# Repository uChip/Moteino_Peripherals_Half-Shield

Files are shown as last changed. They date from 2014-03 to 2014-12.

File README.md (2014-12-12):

# Moteino Peripherals Half-Shield  

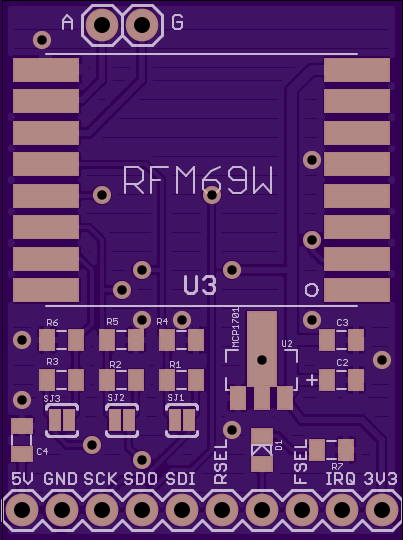
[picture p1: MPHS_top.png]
Moteino Peripherals Half-Shield top side
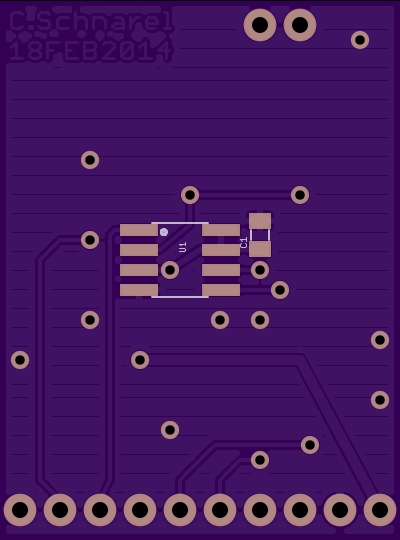
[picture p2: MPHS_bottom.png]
Moteino Peripherals Half-Shield bottom side
___  

After making breakout boards for the RFM12B & [RFM69](https://github.com/uChip/RFM69W_BOB) and getting a taste of what those radios can do, I decided I would like to experiment more with [Felix Rusu's software](http://www.lowpowerlab.com).  Of particular interest is the software that Felix has created that enables an Arduino based device to be reprogrammed remotely and wirelessly**.  Now I could just buy a few of Felix's fine [Moteinos](http://lowpowerlab.com/moteino/), but I already have a bunch of [Unos](https://www.sparkfun.com/products/11021), [Minis](https://www.sparkfun.com/products/11113), [Pro Micros](https://www.sparkfun.com/products/12640) and such.  So instead I decided to do a new version of the radio breakout board that adds the flash memory chip.  While I was at it, I also added the LED on D9 so that code would work too.  

I call the board a half-shield.  That is because it will plug directly into an UNO header (plus a couple of wires) but takes up only half the pins.  

Here is the Moteino Peripherals Half-Shield plugged into an Arduino clone, the [RedBoard](https://www.sparkfun.com/products/11575) from SparkFun.  

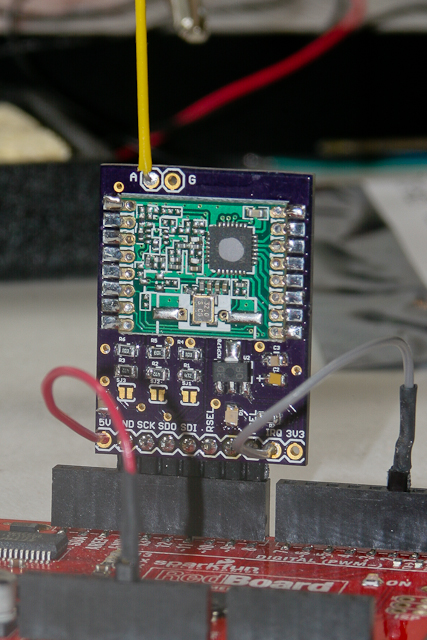
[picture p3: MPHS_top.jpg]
MPHS top side
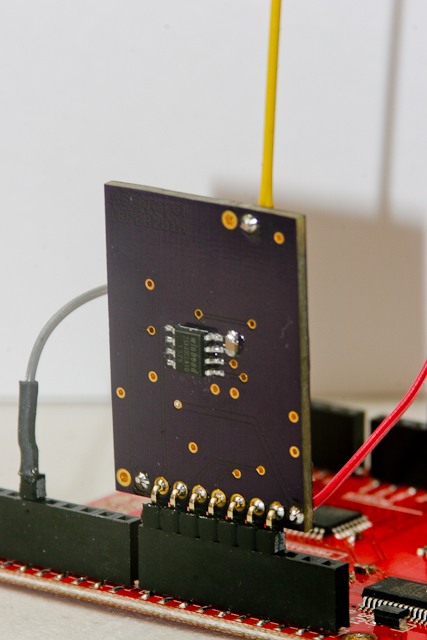
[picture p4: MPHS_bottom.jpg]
MPHS bottom side
___  

This repo includes Eagle CAD PCB design files for the board.  The board converts the RFM69W radio transceiver from SMT to 0.1" breadboard format and provides [optional] level translation for use with 5V controllers.  Note that you cannot solder the RFM12B or the RFM69CW radio modules to this board.  Use the RFM69W or RFM69HW modules instead.  

The board also has provision on the bottom side for a conforming SOIC-8 package flash memory part such as the Winbond W25X40CLSNIG.  

See the following links for Arduino drivers for the RFM69W and flash memory  
  * https://github.com/LowPowerLab/RFM69  
  * https://github.com/LowPowerLab/SPIFlash  

### 5V Hookup  
Hookup of the breakout board to 5V Arduino SPI connection.  All board components populated.  Solder-jumpers left open.  

	Arduino			Half-Shield  
	  5V	-->		  5V  
	  GND	<-->	  GND  
	  D13	-->		  SCK  
	  D12	<--		  SDO  
	  D11	-->		  SDI  
	  D10	-->		  RSEL  
	  D9	-->		  LED  
	  D8	-->		  FSEL  
	  D2	<--		  IRQ  
	  		<--		  3V3  
 
### 3.3V Hookup  
Hookup of the breakout board to 3.3V Arduino SPI connection.  On PCB populate only radio, flash memory, C1, C2 and C3.  Short the pads on the solder-jumpers.  

	Arduino			Half-Shield  
	  NC	 		  5V  
	  GND	<-->	  GND  
	  D13	-->		  SCK  
	  D12	<--		  SDO  
	  D11	-->		  SDI  
	  D10	-->		  RSEL  
	  D9	-->		  LED  
	  D8	-->		  FSEL  
	  D2	<--		  IRQ  
 	  3.3V	-->		  3V3  

## Order PCBs  

You can order this PCB directly from OSH Park.  Click on the following link.  
  * Radio Breakout - http://oshpark.com/shared_projects/AadEx5fd  

See Bill of Materials file in repo for parts list.  

## Status  
  * PCB layout has been tested to be functional using the Low Power Lab example code for RFM69 and SPIFlash.  

## File Formats  

Design files are in "CadSoft EAGLE PCB Design Software" .brd and .sch formats.  
A free version of the software can be downloaded from www.cadsoftusa.com.  

schematic  
schematic  

PCB  
PCB   

## Distribution License  

You may use this PCB design however you like but no liability is accepted.  

## Notes:

** Arduino wireless reprogramming requires a custom bootloader.  Read more about it at http://LowPowerLab.com

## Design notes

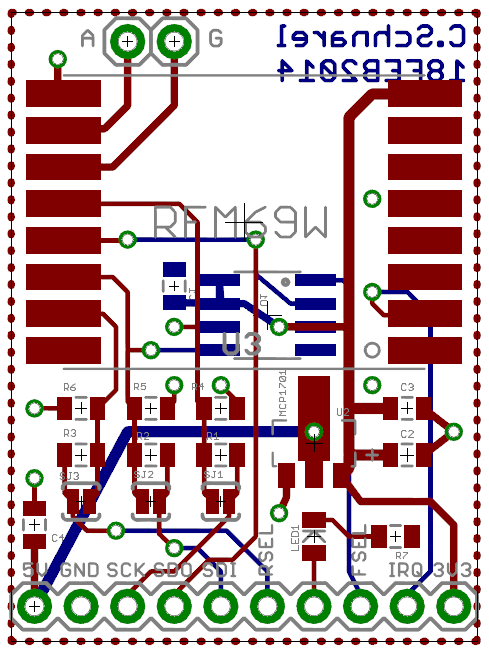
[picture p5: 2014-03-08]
MPHS_brd.PNG

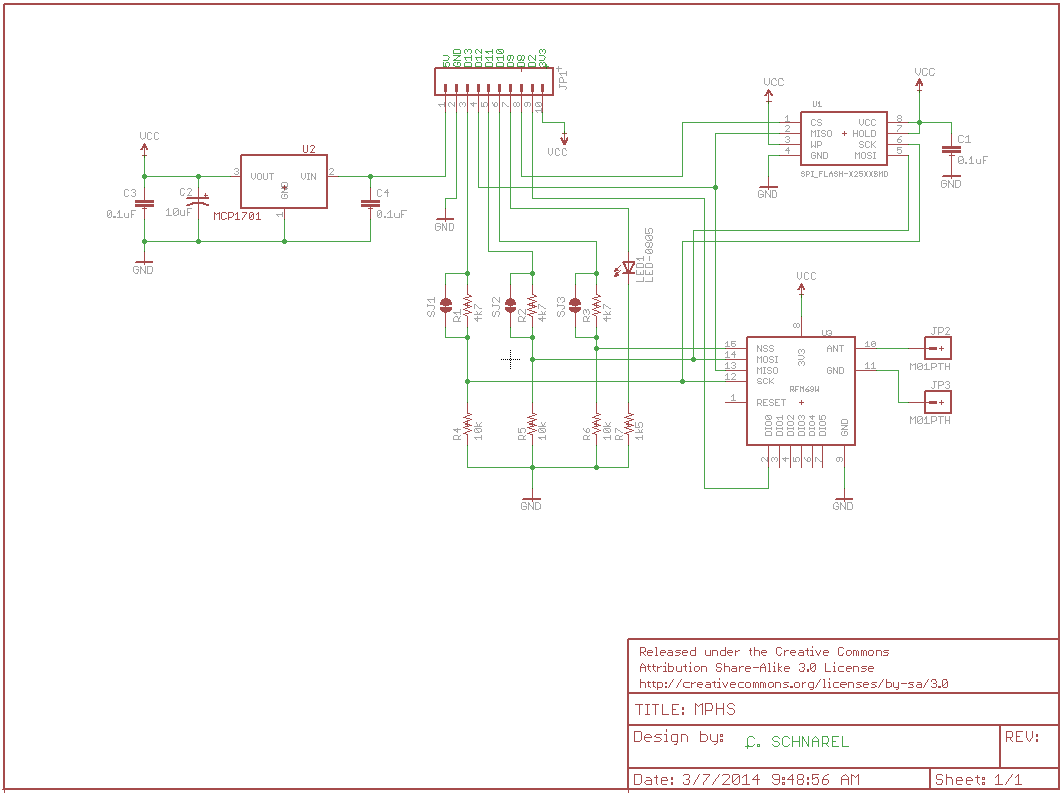
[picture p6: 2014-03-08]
MPHS_sch.PNG

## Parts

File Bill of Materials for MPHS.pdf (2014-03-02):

## Bill of Materials for Moteino Peripherals Half-Shield

## By Component ID

Part | Value | Device | Package | Description | Comment
C1 | 0.1uF | CAP0805 | 0805 | Capacitor
C2 | 10uF | CAP_POL0805 | 0805-POL | Capacitor, Tantalum | Could likely substitute electrolytic with no ill effects.
C3 | 0.1uF | CAP0805 | 0805 | Capacitor
C4 | 0.1uF | CAP0805 | 0805 | Capacitor
JP1 | 10 or 7 pins | 1X07_RIGHT_ANGLE | | Header 10 or 7 | To plug into a breadboard populate all 10 pins. To plug into Arduino as a shield populate 7 pins.
R1 | 4k7 | RESISTOR0805-RES | 0805 | Resistor
R2 | 4k7 | RESISTOR0805-RES | 0805 | Resistor
R3 | 4k7 | RESISTOR0805-RES | 0805 | Resistor
R4 | 10k | RESISTOR0805-RES | 0805 | Resistor
R5 | 10k | RESISTOR0805-RES | 0805 | Resistor
R6 | 10k | RESISTOR0805-RES | 0805 | Resistor
R7 | 1k5 | RESISTOR0805-RES | 0805 | Resistor
U1 | SPI_FLASH | SPI_FLASH_X25XXSMD | SO08 | IC | 8pin SPI Flash series X25XX
U2 | MCP1701 | MCP1701 | SOT-89 | Voltage Regulator, LDO | 3.3volt
U3 | RFM69W | RFM69W | Module | Radio Transceiver Module | Untested, but you can likely substitute RFM69HW for more power.

## Order List

Qty | Parts | Value | Mfg Part # | Description / Vendor
1 | JP1 | 10 or 8-pins | | Break Away Male Headers - Right Angle https://www.sparkfun.com/products/553[/
1 | PCB | | Moteino Peripherals Half-Shield | http://oshpark.com/shared_projects/AadEx5fd
3 | C1, C3, C4 | 0.1uF | C2012X7R2A104K125AA | CAP CER 0.1UF 100V 10% X7R 0805 Digi-Key #445-1418-1-ND
3 | R4, R5, R6 | 10k | ERJ-6GEYJ103V | RES 10K OHM 1/8W 5% 0805 SMD Digi-Key #P10KACT-ND
1 | C2 | 10uF | F951A106MRAAQ2 | CAP TANT 10UF 10V 20% 0805 Digi-Key #478-8418-1-ND
3 | R1, R2, R3 | 4k7 | ERJ-6GEYJ472V | RES 4.7K OHM 1/8W 5% 0805 SMD Digi-Key #P4.7KACT-ND
1 | R7 | 1k5 | RC2012J152CS | RES 1.5K OHM 1/8W 5% 0805 SMD Digi-Key #1276-5533-1-ND
1 | U2 | MCP1701 | MCP1701AT-3302I/MB | IC REG LDO 3.3V 0.15A SOT89-3 Digi-Key #MCP1701AT-3302I/MBCT-ND
1 | U3 | RFM69W | RFM69W-S2 | http://lowpowerlab.com/shop/RFM69W
1 | U1 | 4Mbit Flash | W25X40CLSNIG | IC FLASH 4MBIT 104MHZ 8SOIC Digi-Key #W25X40CLSNIG-ND

Note that all parts are "or equivalent". These are the parts I tested with, but you can probably substitute parts with no impact on performance. For instance, any 0805 package 10k resistor would be fine.

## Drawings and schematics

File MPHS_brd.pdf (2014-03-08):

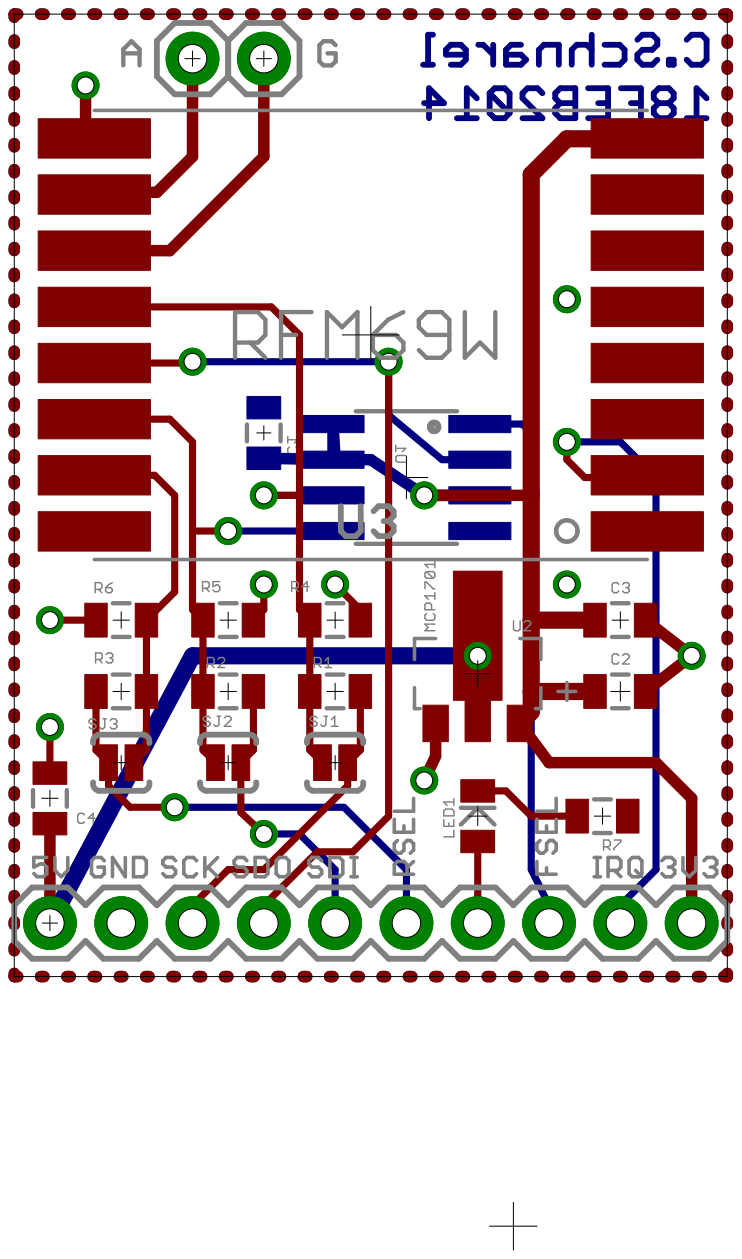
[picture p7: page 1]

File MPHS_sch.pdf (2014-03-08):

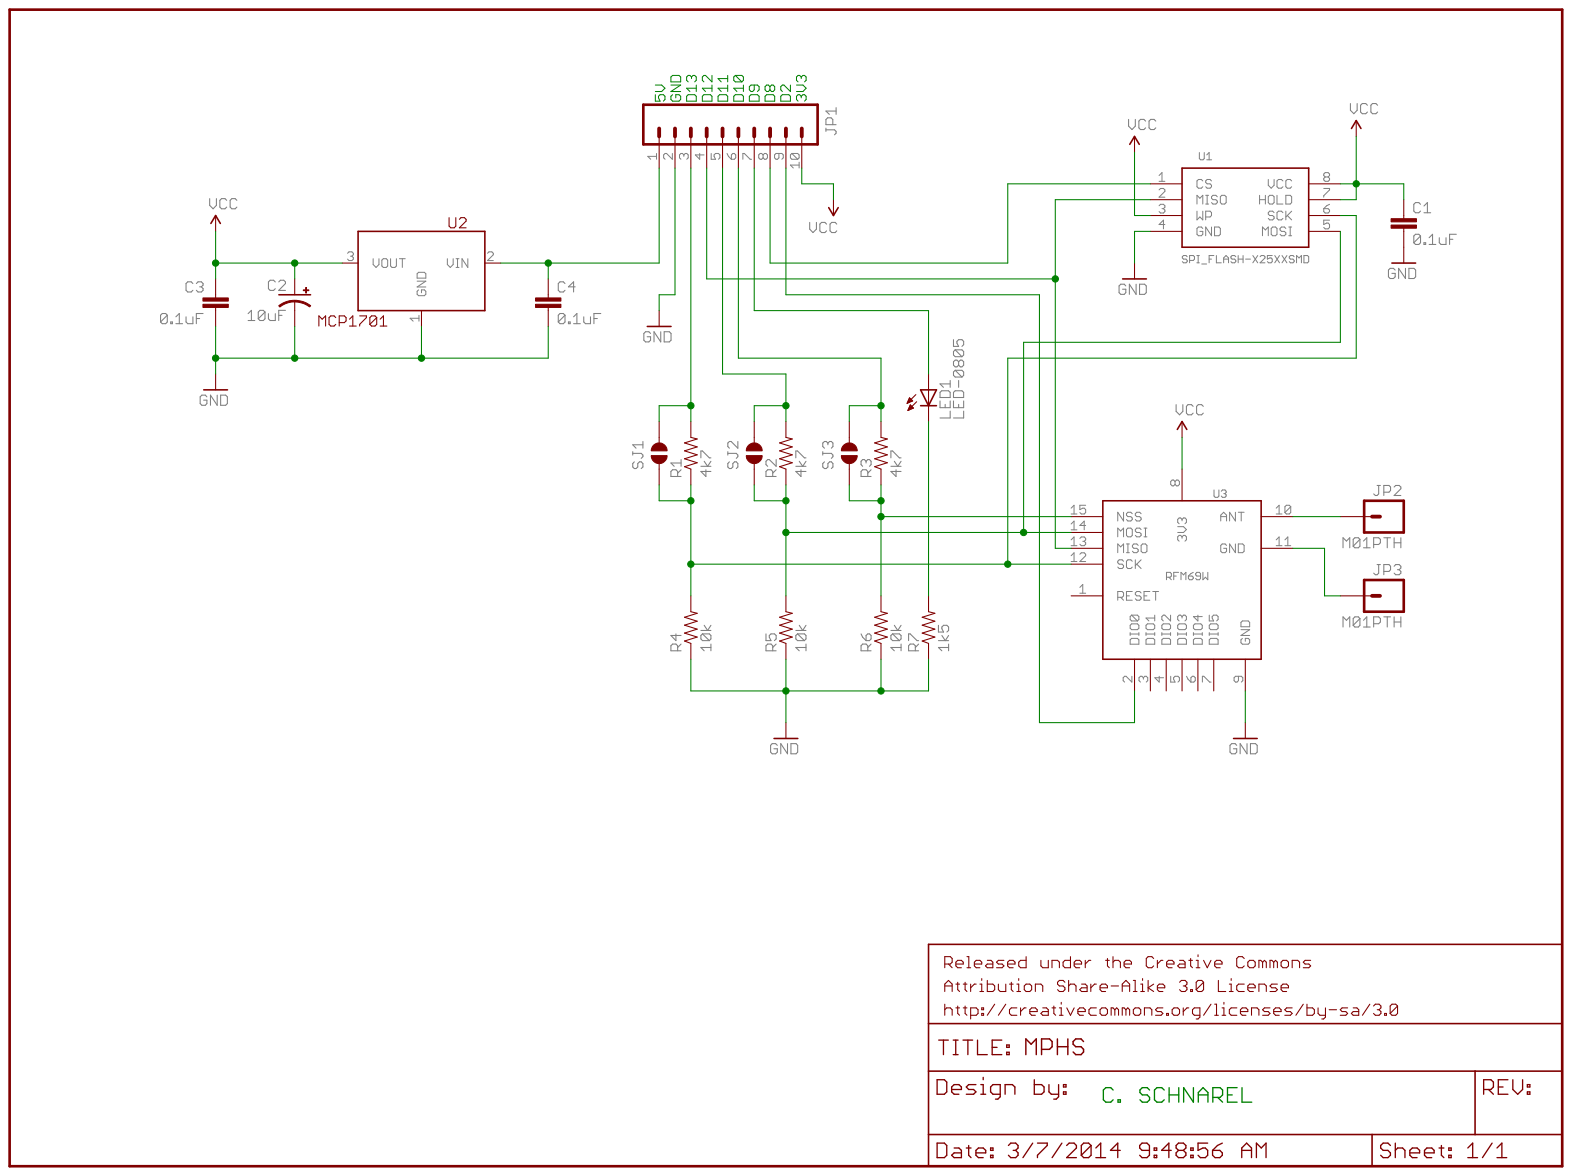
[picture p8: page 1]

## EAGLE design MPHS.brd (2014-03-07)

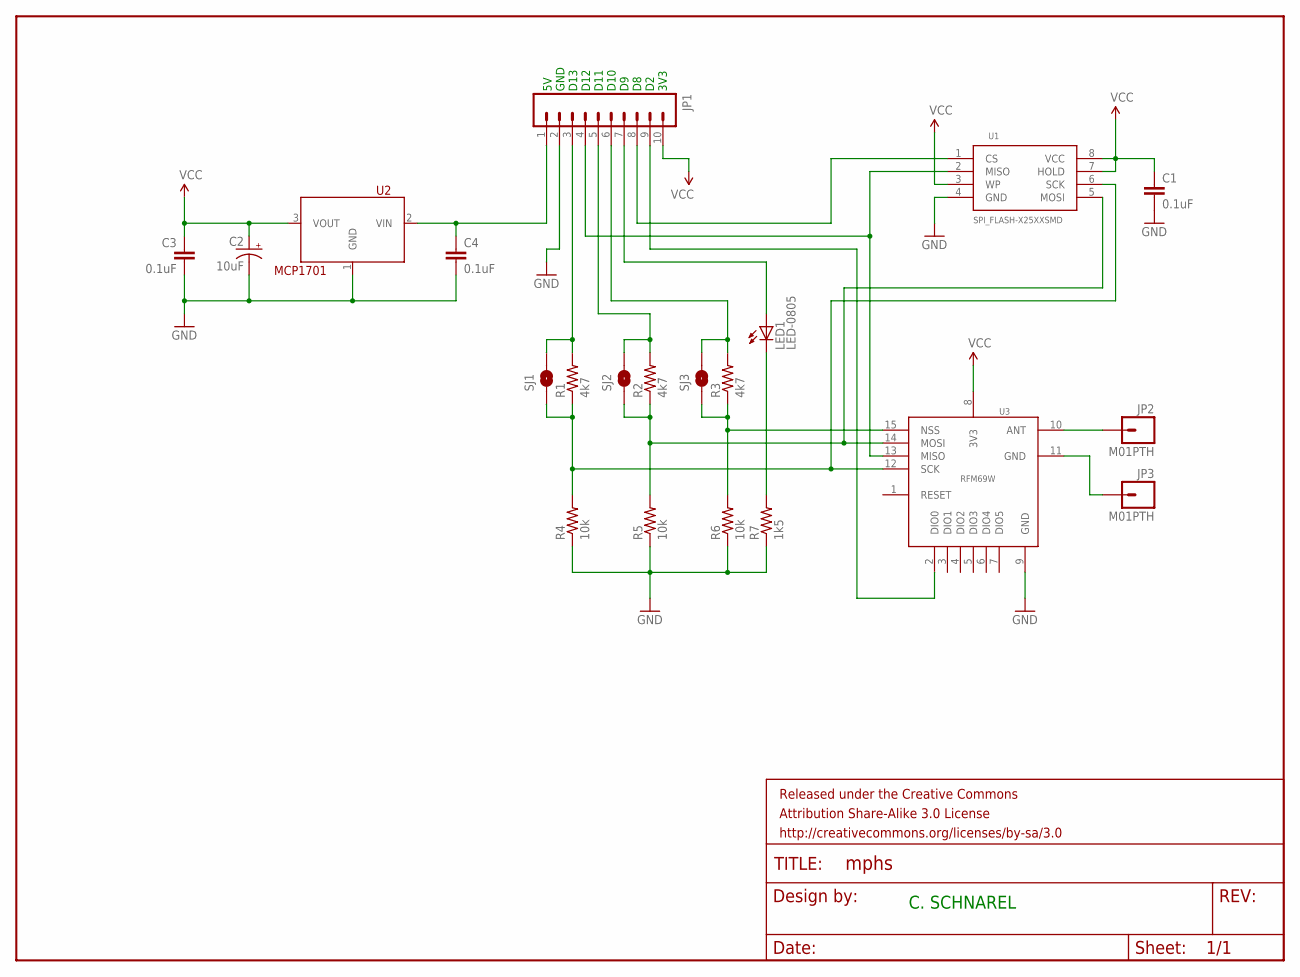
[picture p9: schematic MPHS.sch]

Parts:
C1, C3, C4: 0.1uF; 0805
C2: 10uF; 0805-POL
FRAME1: FRAME-LETTER; CREATIVE_COMMONS
JP1: M10"; 1X10
JP2, JP3: M01PTH; 1X01
LED1: LED-0805; 0805-LED
R1, R2, R3: 4k7; 0805
R4, R5, R6: 10k; 0805
R7: 1k5; 0805
SJ1, SJ2, SJ3: SOLDERJUMPERNO; SJ_2S-NO
U1: SPI_FLASH-X25XXSMD; SO08
U2: MCP1701; SOT-89
U3: RFM69W

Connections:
GND: C1.2, C2.2 (-), C3.2, C4.2, JP1.2, R4.1, R5.1, R6.1, R7.1, U1.4 (GND), U2.1 (GND), U3.9 (GND)
unnamed: R3.1, R6.2, SJ3.1, U3.15 (NSS)
unnamed: C4.1, JP1.1, U2.2 (VIN)
unnamed: JP1.4, U1.2 (MISO), U3.13 (MISO)
unnamed: JP1.9, U3.2 (DIO0)
unnamed: R2.1, R5.2, SJ2.1, U1.5 (MOSI), U3.14 (MOSI)
unnamed: JP1.3, R1.2, SJ1.2
unnamed: JP1.5, R2.2, SJ2.2
unnamed: JP1.6, R3.2, SJ3.2
unnamed: R1.1, R4.2, SJ1.1, U1.6 (SCK), U3.12 (SCK)
unnamed: JP2.1, U3.10 (ANT)
unnamed: JP3.1, U3.11 (GND)
unnamed: JP1.7, LED1.A
unnamed: JP1.8, U1.1 (CS)
unnamed: LED1.C, R7.2
VCC: C1.1, C2.1 (+), C3.1, JP1.10, U1.3 (WP), U1.7 (HOLD), U1.8 (VCC), U2.3 (VOUT), U3.8 (3V3)

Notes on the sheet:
C. SCHNAREL
5V GND D13 D12 D11 D10 D9 D8 D2 3V3

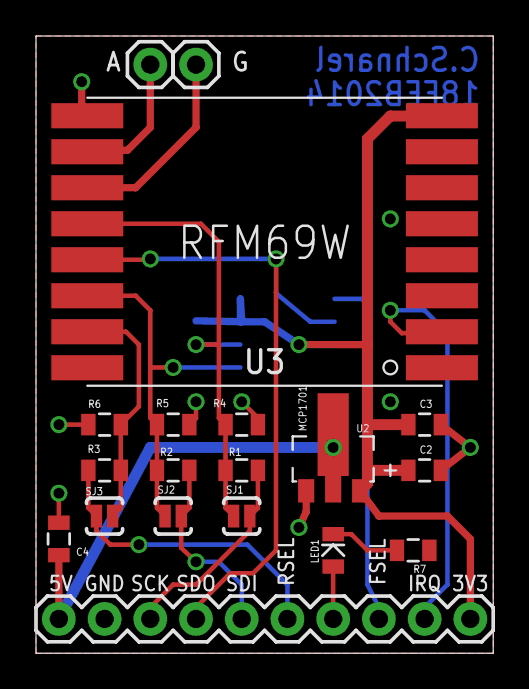
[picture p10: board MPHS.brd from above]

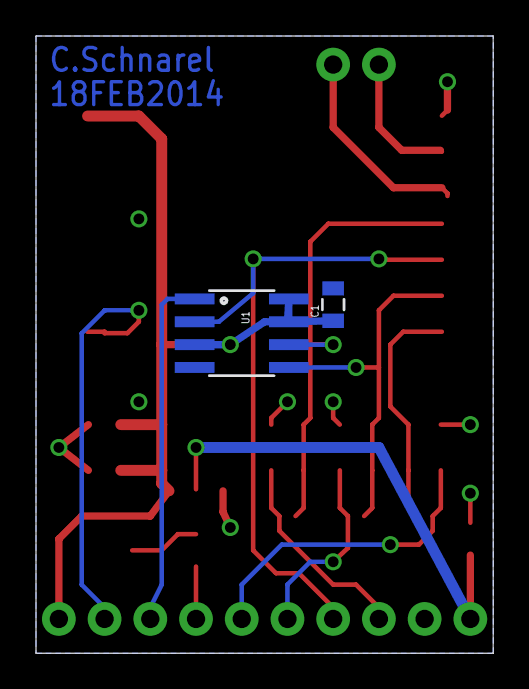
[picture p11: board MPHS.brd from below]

Board: 2 copper layers, 25.4 x 34.3 mm, 22 parts (2 on the bottom side), 16 nets.

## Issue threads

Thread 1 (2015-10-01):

RFM69CW on this PCB

ropolik, 2015-10-01:
Hi uChip,

this board is excellent! Do you have design of board for RFM69CW ?
I have RFM69CW and want use RFM69CW on this board and like me this half-shiled with serial flash which I have too.

Many thanks for answer

uChip, 2015-10-01:
I have not worked with the RFM69CW, however from a very brief scan of the datasheet it appears to be very similar from a signal I/O perspective.  I would be willing to create a RFM69CW package and board layout, but there would be caveats.  The first would be that you would need to test and verify the board yourself since I don't have an RFM69CW, nor do I really have time for another project just now.  The other caveat would be that I have no idea if the RFM69CW programs the same as the other modules.  Any software modifications required, you would need to do yourself.  If that is acceptable, let me know and I'll take a crack at the package and board.
  - Chip

uChip, 2015-10-01:
Oops.  Leaving issue open until ropolik responds.

ropolik, 2015-10-02:
RFM69CW by function is same like RFM69W. But letter C indicates that RFM69CW is backward Compatibility with pinout of RFM12B.
I can try it (I have several RFM69CW ), but I do not have the PCB or design of PCB in Eagle.
I can send the library of RFM69CW for Eagle.

uChip, 2015-10-02:
Is it footprint compatible with the 12B?  I have an Eagle library for that.  Or go ahead and send what you have.  Thanks.

ropolik, 2015-10-02:
Yes. Footprint is compatible with the RFM12B. Where I can send the library to you?

Right side on scheme from bottom to top: Pin 1-ANT, 2-VCC, 3-GND, 4-DIO3, 5-MOSI, 6-SCK, 7-NSS
Left side on scheme from bottom to top: Pin 14-GND, 13-RESET, 12-DIO5, 11-DIO1, 10-DIO2, 9-DIO0, 8-MISO.
RFM69CW and RFM12B is have same dimensions of case and same footprint.

ropolik, 2015-10-02:
http://www.hoperf.com/rf/fsk_module/RFM69CW.htm

uChip, 2015-10-02:
Ok.  You will soon find a new schematic and board files in this repo.  Check both carefully.  I used the RFM12B footprint from the orginal Low Power Lab breakout board as I already had that lying around.  If the RFM69C is truly compatible then all should be good.  Again, check the files carefully as I have not built the board.  You are welcome to take the board file and submit it to fab, or I can submit it and share it out.  Let me know if you want me to do that.
I'll leave this open for a while to let you confirm the design.

ropolik, 2015-10-02:
Yes. If I found on this project new design of the PCB then I am try made in fab the new PCB with RFM69CW.  I try the new PCB and write feedback of results.

Many thanks for new early PCB :-)

Best Regards

ropolik, 2015-10-03:
I am download new design of PCB. By first look I see than ground of antenne is not connected to ground on PCB.
I do not know which layer of PCB solves grounding. I do not know how is connected to ground next points.
Missing wire on PCB between GND of header (pin 2) and C4, R6 on Top side of PCB.
On the bottom side of PCB is missing wire between GND of header (pin 2) and pin 1 of U2 (LDO regulator) - via hole of pin 1 of U2.
Not connected ground wire of C2 and C3 on top side of PCB. May be connected to GND on bottom side of PCB. And next grounded pins, pads, etc.

I have some LDO AMS1117-3.3V in case SOT-223 which is have reversed IN and OUT VCC. From left to right from view of top case pinout is 1-GND, 2-OUT, 3-IN. Would you make PCB design with this LDO?

Many, many thanks for your answer and assistance.

uChip, 2015-10-03:
Grounds are connected by a flood.  Click on the "Ratsnest" button to have the flood redrawn.  Also, I just checked the 1117 and it has the same pinout as the 1701, but they are not the same package.  The 1117 is in the SparkFun library.  You are welcome to change it if you like.

ropolik, 2015-10-03:
Yes. I want use AMS1117 LDO. Would you make another design of PCB with AMS1117 3.3v
?

ropolik, 2015-10-04:
I am look to the sheet again (http://www.advanced-monolithic.com/pdf/ds1117.pdf). AMS1117 in package SOT-223 from top view is have on middle pin V-OUT (output) and on the right pin is have V-IN (input).
MCP 1701 (sheer http://ww1.microchip.com/downloads/en/DeviceDoc/21874b.pdf) from top view is have on middle pin V-IN (INPUT) and on the right pin is have V-OUT (output).

You say truth that package SOT-223 (AMS1117) is bigger than package SOT-89 (MCP 1701). I am sorry, my error.

Would you make another design of PCB with AMS1117 3.3v (package SOT-223 and midle and right pin is different than MCP 1701) ?

Many, many thanks for your assistance!

Best Regards

uChip, 2015-10-04:
I have made the change but the layout is now quite cramped.  I don't like it.  You should take the files with the change then I will take them down again.

  - Chip

ropolik, 2015-10-05:
Yes, I have the new files with PCB and scheme. Will do you another new variant of PCB?

uChip, 2015-10-05:
The latest version posted yesterday has the change to the 1117 voltage regulator.  I do not plan on another version.

  - Chip

ropolik, 2015-10-05:
Ok. I asked you in reaction that you wrote: " I don't like it. ".

I try made the new PCB and test it. I write later how this new PCB is works.

Many thanks for your help!

uChip, 2015-10-05:
Ah.  I understand now.
Improving the layout could probably achieved with more work, but as I noted earlier, I don't really have time for a more involved project right now.  Nor do I see a great advantage to using the RFM69C and 1117 over those of my original layout.  I hope that the board works for you but I will pull down this variant now that you have it.  I don't want to confuse other readers with variants that are not really supported.  Good luck with your project.

  - Chip

ropolik, 2015-10-05:
uChip, I printed the PCB and I placed the components (RFM69CW and LDO AMS1117). I would need more space on the PCB between RFM and antenna input and next space between RFM and AMS1117. On the photo is see the place which I need more space. Would you made PCB with this modifications?
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

Do you have PayPal account? I want send to you some money for your help.

uChip, 2015-10-06:
Yes, that is the cramping I spoke of.  Although it could be assembled as is, I think the best solution is to make the board about 2 tenths of an inch taller.  I will take a look at doing that.

Since I am not verifying the design or affirming that it will even work, it would be inappropriate to take money for it.  Thank you for the thought.

  - Chip

uChip, 2015-10-07:
I extended the board by 0.1 inches and moved the radio and antenna connections up to spread things apart.  Print this one out as you did before and check the size.  I hope it is enough but if not I will move it some more.
Instead of adding the board to the repo again, I have attached it here.  To attach the file I had to change the file type to text.  After you download it change the file type back to brd so that Eagle recognizes it.
[MPHS-RFM69C.txt](https://github.com/uChip/Moteino_Peripherals_Half-Shield/files/9038/MPHS-RFM69C.txt)

  - Chip

uChip, 2015-10-13:
I haven't heard back from ropolik. I will open this issue again in case that is needed to get messages sent.  ropolik, please see previous comment and respond if new layout works.
  - Chip

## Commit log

2014-03-02 Initial Commit
    Half-Shield board for RFM69, flash mem and LED arranged per Moteino I/O
    pins.
    [MPHS.brd, MPHS.sch]
2014-03-02 Adding BOM
2014-03-02 Updated BOM & README
2014-03-07 New photo with LED installed (parts arrived)
    Changed board layout and schematic to have proper LED component. No
    change to actual BOM or circuit. Shot new photo of board with LED
    installed.
    [MPHS.brd, MPHS.sch]
2014-03-08 README updates
    Added pdf versions of schematic and board for viewing without EagleCAD
2015-10-02 Created board variant for RFM69C - NOT TESTED!!!
    [MPHS-RFM69C.brd, MPHS-RFM69C.sch]
2015-10-04 Changed VReg to 1117
    [MPHS-RFM69C.brd, MPHS-RFM69C.sch]
2015-10-05 Removing Unsupported RFM69C variant
    [MPHS-RFM69C.brd, MPHS-RFM69C.sch]

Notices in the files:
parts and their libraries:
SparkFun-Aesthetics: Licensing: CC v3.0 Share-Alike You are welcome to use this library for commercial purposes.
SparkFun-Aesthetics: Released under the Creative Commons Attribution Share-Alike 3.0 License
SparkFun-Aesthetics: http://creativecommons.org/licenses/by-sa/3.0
